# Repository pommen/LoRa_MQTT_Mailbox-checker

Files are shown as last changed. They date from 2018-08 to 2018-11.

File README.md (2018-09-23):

# LoRa_MQTT_Mailbox-checker
My version of a mailbox check using LoRa RFM95 module on a custom arduino pro mini with 18650battery. communicating with a ESP8266 

ISP pins on the board mounted on the mailbox is mirrored. If used, either burn boot loader before mounting the 328p. Or use dupoint wires to connect to the programmer.

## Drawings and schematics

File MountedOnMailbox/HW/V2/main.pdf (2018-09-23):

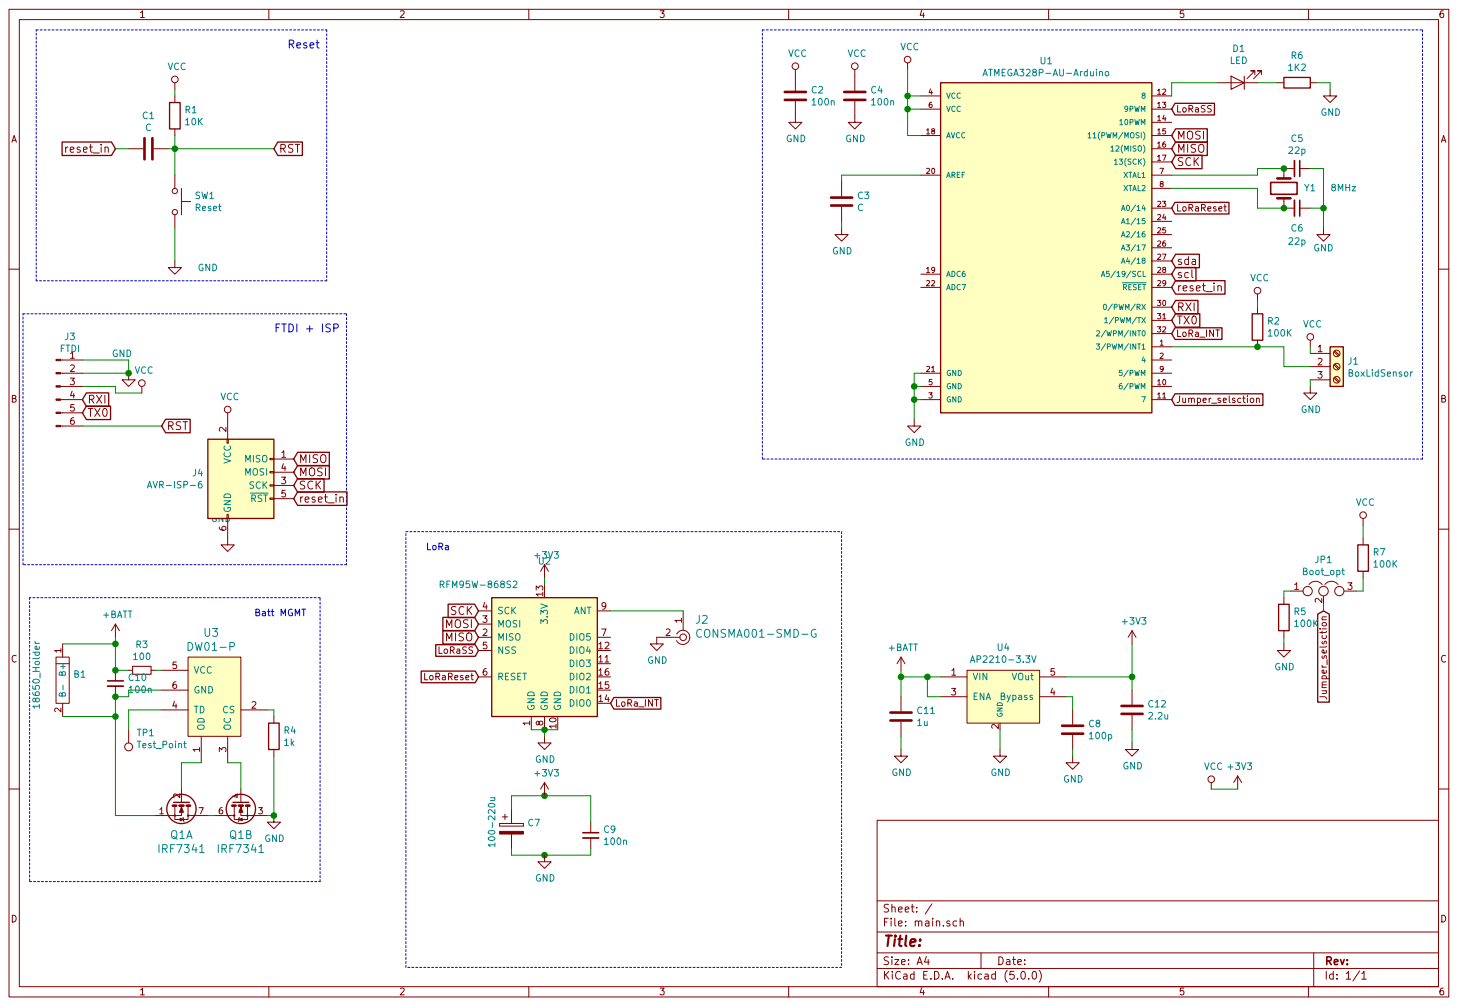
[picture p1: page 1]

scl sda Reset RST

2 SCK 3 MOSI 4 RST 5 GND

1 GND 10 DIO3 11 DIO4 12 3.3V 13 DIO0 14 DIO1 15 DIO2 16 MISO 2 MOSI 3 SCK 4 NSS 5 RESET 6 DIO5 7 GND
SCK

Id: 1/1 Title: File: main.sch Sheet: /

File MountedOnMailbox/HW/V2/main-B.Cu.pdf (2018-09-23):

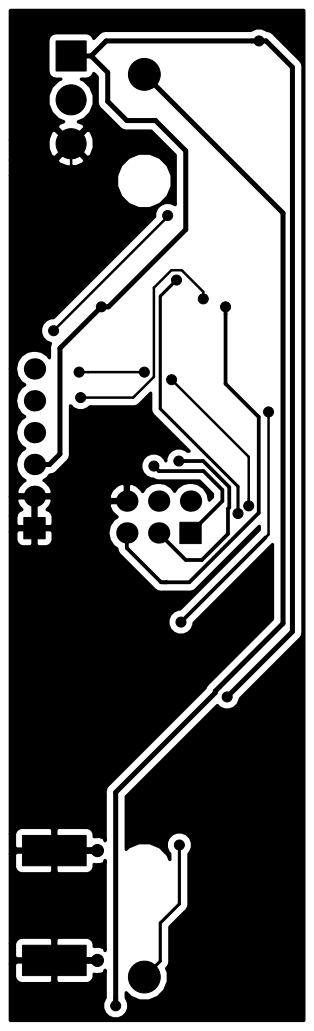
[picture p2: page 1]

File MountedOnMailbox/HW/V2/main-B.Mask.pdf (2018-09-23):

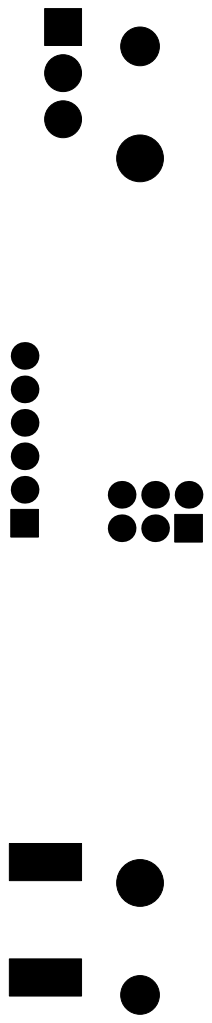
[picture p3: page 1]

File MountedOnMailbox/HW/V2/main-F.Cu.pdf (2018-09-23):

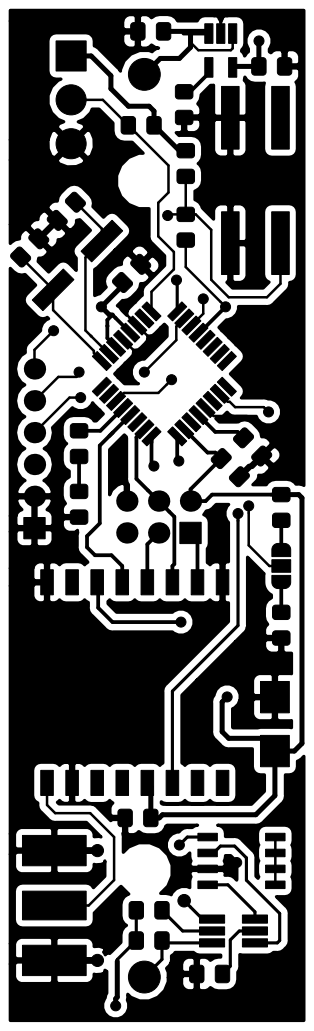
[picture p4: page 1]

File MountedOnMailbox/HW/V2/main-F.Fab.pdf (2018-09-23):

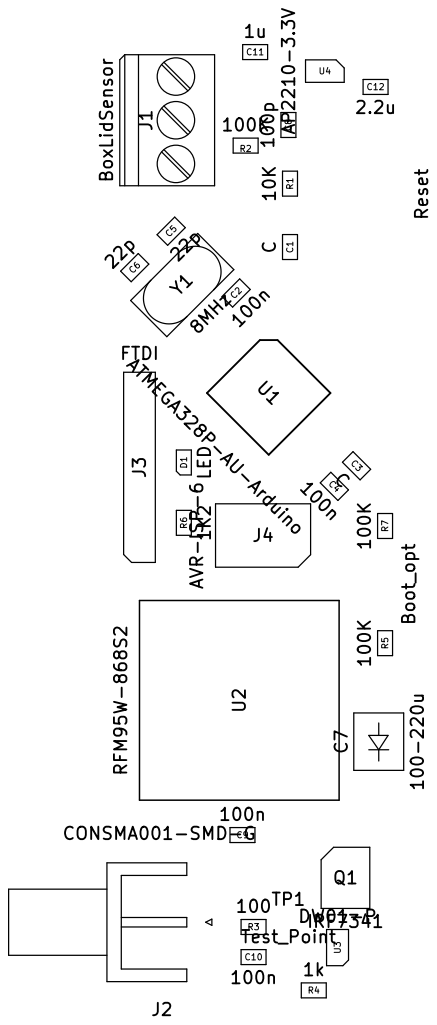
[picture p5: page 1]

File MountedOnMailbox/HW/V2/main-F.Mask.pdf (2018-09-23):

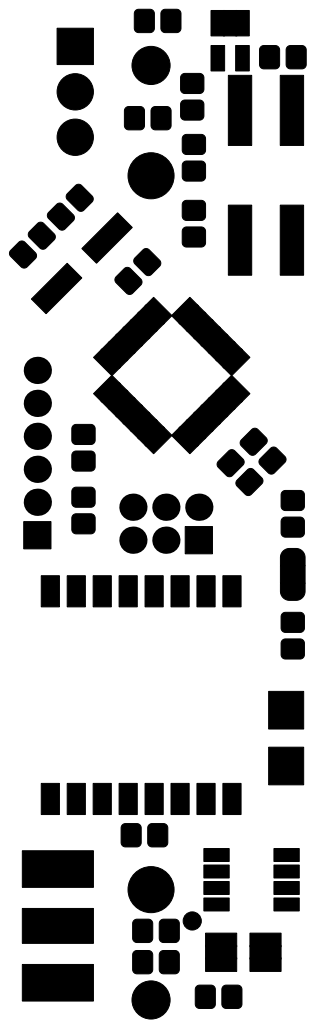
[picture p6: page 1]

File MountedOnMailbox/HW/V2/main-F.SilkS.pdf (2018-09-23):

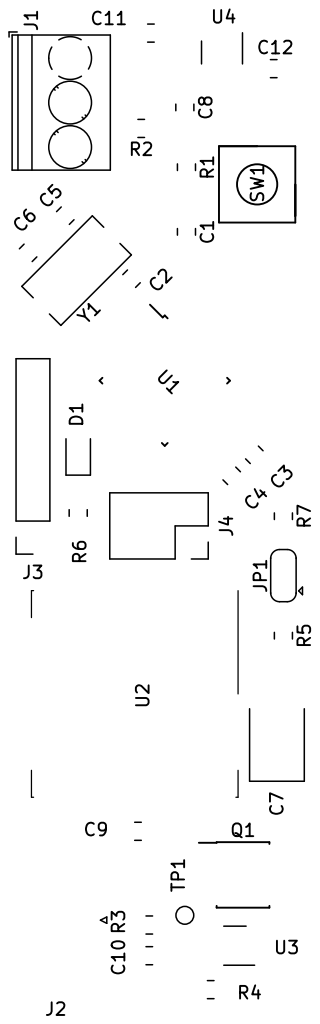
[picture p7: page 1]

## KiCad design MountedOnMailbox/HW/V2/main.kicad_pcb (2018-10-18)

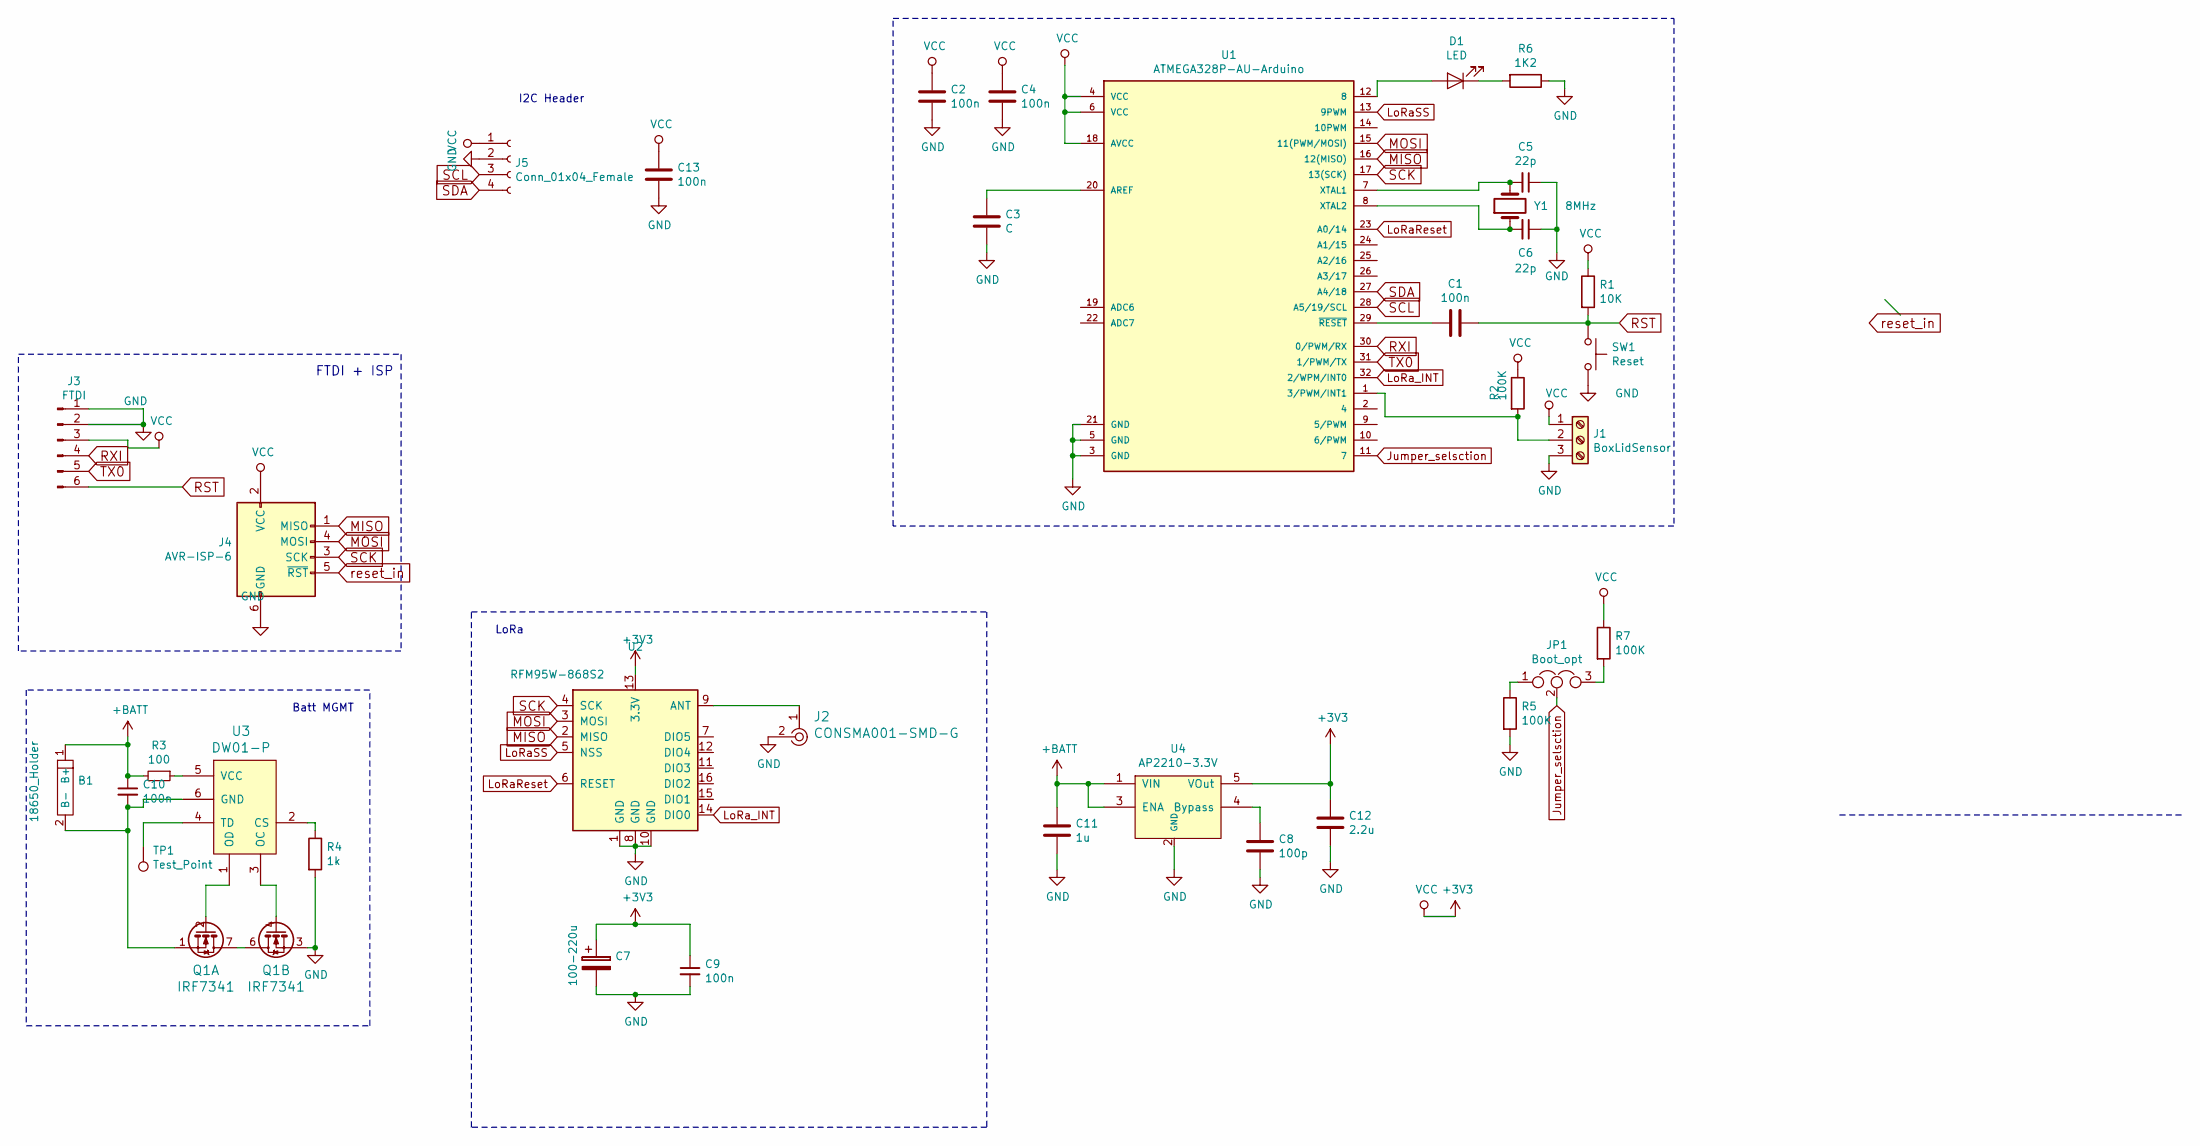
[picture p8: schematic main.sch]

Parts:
B1: 18650_Holder; 18650-PC2_holder
C1, C2, C4, C9, C10, C13: 100n; C_0805_2012Metric_Pad1.15x1.40mm_HandSolder
C3: C; C_0805_2012Metric_Pad1.15x1.40mm_HandSolder
C5, C6: 22p; C_0805_2012Metric_Pad1.15x1.40mm_HandSolder
C7: 100-220u; D_SMB
C8: 100p; C_0805_2012Metric_Pad1.15x1.40mm_HandSolder
C11: 1u; C_0805_2012Metric_Pad1.15x1.40mm_HandSolder
C12: 2.2u; C_0805_2012Metric_Pad1.15x1.40mm_HandSolder
D1: LED; LED_0805_2012Metric_Pad1.15x1.40mm_HandSolder
J1: BoxLidSensor; TerminalBlock_Phoenix_PT-1,5-3-3.5-H_1x03_P3.50mm_Horizontal
J2: CONSMA001-SMD-G; SMA_edge connector; MPN CONSMA001-SMD-G; Digi-Key_PN CONSMA001-SMD-G-ND
J3: FTDI; PinSocket_1x06_P2.54mm_Vertical
J4: AVR-ISP-6; PinSocket_2x03_P2.54mm_Vertical
J5: Conn_01x04_Female; PinHeader_1x04_P2.54mm_Vertical
JP1: Boot_opt; SolderJumper-3_P1.3mm_Open_RoundedPad1.0x1.5mm
Q1: IRF7341; SOIC-8_3.9x4.9mm_P1.27mm
R1: 10K; R_0805_2012Metric_Pad1.15x1.40mm_HandSolder
R2, R5, R7: 100K; R_0805_2012Metric_Pad1.15x1.40mm_HandSolder
R3: 100; R_0805_2012Metric_Pad1.15x1.40mm_HandSolder
R4: 1k; R_0805_2012Metric_Pad1.15x1.40mm_HandSolder
R6: 1K2; R_0805_2012Metric_Pad1.15x1.40mm_HandSolder
SW1: Reset; PushBTN KSC241G
TP1: Test_Point; TestPoint_Pad_D1.0mm
U1: ATMEGA328P-AU-Arduino; TQFP-32_7x7mm_P0.8mm
U2: RFM95W-868S2; HOPERF_RFM9XW_SMD
U3: DW01-P; TSOT-23-6_HandSoldering
U4: AP2210-3.3V; SOT-23-5_HandSoldering
Y1: 8MHz; Crystal_SMD_ECS_CSM3X-2Pin_7.6x4.1mm

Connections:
+3V3: C2.1, C4.1, C7.1, C9.1, C12.1, C13.1, J1.1, J3.3, J4.2 (VCC), J5.1, R1.1, R2.1, R7.1, U1.4 (VCC), U1.6 (VCC), U1.18 (AVCC), U2.13 (3.3V), U4.5 (VOut)
+BATT: B1.1 (B+), C10.1, C11.1, R3.2, U4.1 (VIN), U4.3 (ENA)
GND: C2.2, C3.2, C4.2, C5.1, C6.1, C7.2, C8.2, C9.2, C11.2, C12.2, C13.2, J1.3, J2.2, J3.1, J3.2, J4.6 (GND), J5.2, Q1.3, R4.2, R5.2, R6.1, SW1.2, U1.3 (GND), U1.5 (GND), U1.21 (GND), U2.1 (GND), U2.8 (GND), U2.10 (GND), U4.2 (GND)
Jumper_selsction: JP1.2, U1.11 (7)
LoRaReset: U1.23 (A0/14), U2.6 (RESET)
LoRaSS: U1.13 (9PWM), U2.5 (NSS)
LoRa_INT: U1.32 (2/WPM/INT0), U2.14 (DIO0)
MISO: J4.1 (MISO), U1.16 (12(MISO)), U2.2 (MISO)
MOSI: J4.4 (MOSI), U1.15 (11(PWM/MOSI)), U2.3 (MOSI)
unnamed: B1.2 (B-), C10.2, Q1.1, U3.6 (GND)
unnamed: C1.2, U1.29 (~RESET~)
unnamed: C3.1, U1.20 (AREF)
unnamed: C5.2, U1.7 (XTAL1), Y1.2
unnamed: C6.2, U1.8 (XTAL2), Y1.1
unnamed: C8.1, U4.4 (Bypass)
unnamed: D1.1 (K), R6.2
unnamed: D1.2 (A), U1.12 (8)
unnamed: J1.2, R2.2, U1.1 (3/PWM/INT1)
unnamed: J2.1, U2.9 (ANT)
unnamed: JP1.1, R5.1
unnamed: JP1.3, R7.2
unnamed: Q1.2, U3.1 (OD)
unnamed: Q1.4, U3.3 (OC)
unnamed: Q1.5, Q1.6, Q1.7, Q1.8
unnamed: R3.1, U3.5 (VCC)
unnamed: R4.1, U3.2 (CS)
unnamed: TP1.1, U3.4 (TD)
RST: C1.1, J3.6, R1.2, SW1.1
RXI: J3.4, U1.30 (0/PWM/RX)
SCK: J4.3 (SCK), U1.17 (13(SCK)), U2.4 (SCK)
SCL: J5.3, U1.28 (A5/19/SCL)
SDA: J5.4, U1.27 (A4/18)
TX0: J3.5, U1.31 (1/PWM/TX)
reset_in: J4.5 (~RST)

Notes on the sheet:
FTDI + ISP
Batt MGMT
LoRa
I2C Header

Board: 2 copper layers, 36 parts (1 on the bottom side), 33 nets, no tracks yet.

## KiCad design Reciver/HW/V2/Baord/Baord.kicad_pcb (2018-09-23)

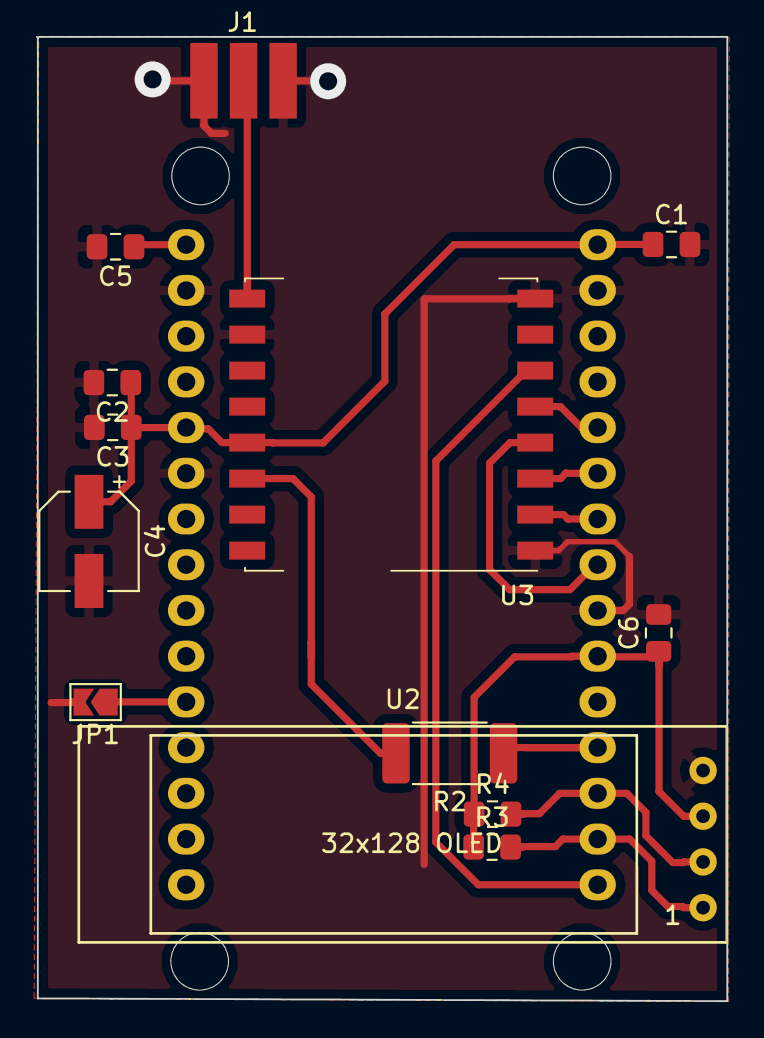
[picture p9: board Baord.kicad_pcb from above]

Board: 2 copper layers, 38.4 x 53.6 mm, 14 parts (1 on the bottom side), 14 nets.

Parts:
C1, C2, C5, C6: 100n; C_0805_2012Metric_Pad1.15x1.40mm_HandSolder
C3: C; C_0805_2012Metric_Pad1.15x1.40mm_HandSolder
C4: CP; CP_Elec_5x5.9
J1: Edge_Connector; SMA_edge connector
JP1: Jumper; SolderJumper-2_P1.3mm_Open_TrianglePad1.0x1.5mm
R2: 0R; R_2512_6332Metric_Pad1.52x3.35mm_HandSolder
R3, R4: 10K; R_0805_2012Metric_Pad1.15x1.40mm_HandSolder
U1: NodeMCU_1.0_(ESP-12E); NodeMCU_Amica_R2
U2: OLED_128x32_i2c; OLED_128x32_I2C
U3: RFM95W-868S2; HOPERF_RFM9XW_SMD

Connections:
CS: U1.20, U3.5
GND: C1.2, C2.2, C3.2, C4.2, C5.2, C6.2, J1.2, JP1.2, U1.10, U1.14, U1.17, U1.24, U2.4, U3.1, U3.8, U3.10
I2C_SCL: R4.2, U1.28, U2.2
I2C_SDA: R3.2, U1.29, U2.1
INT: R2.1, U1.27
MISO: U1.22, U3.2
MOSI: U1.21, U3.3
unnamed: C5.1, U1.15
unnamed: J1.1, U3.9
unnamed: JP1.1, U1.5
unnamed: R2.2, U3.14
RESET: U1.30, U3.6
SCK: U1.23, U3.4
VCC: C1.1, C2.1, C3.1, C4.1, C6.1, R3.1, R4.1, U1.11, U1.16, U1.25, U2.3, U3.13

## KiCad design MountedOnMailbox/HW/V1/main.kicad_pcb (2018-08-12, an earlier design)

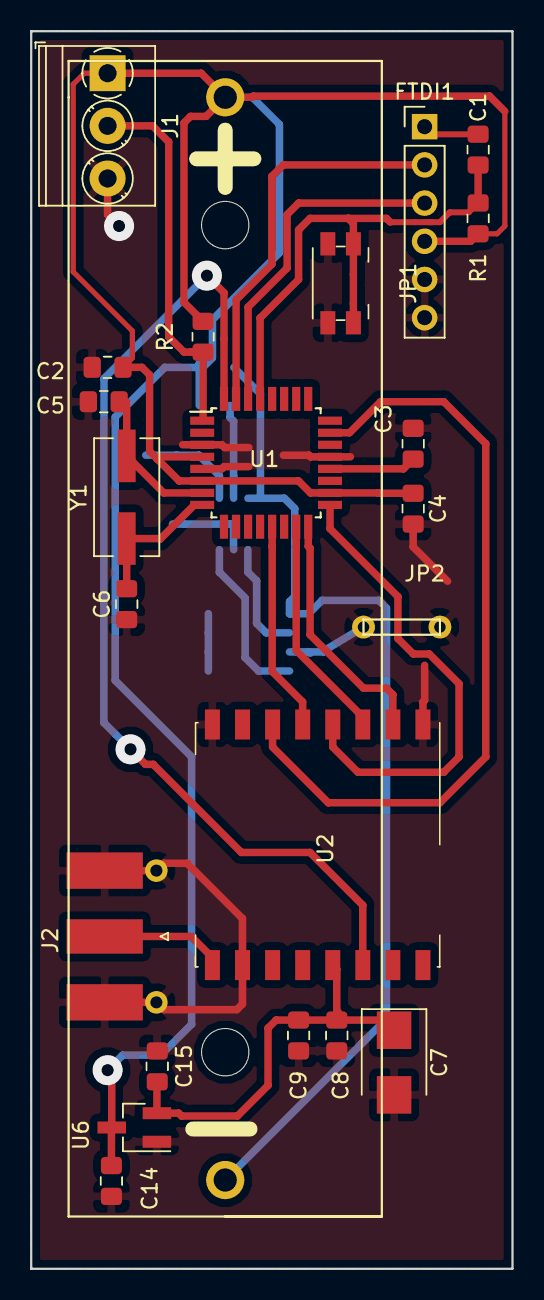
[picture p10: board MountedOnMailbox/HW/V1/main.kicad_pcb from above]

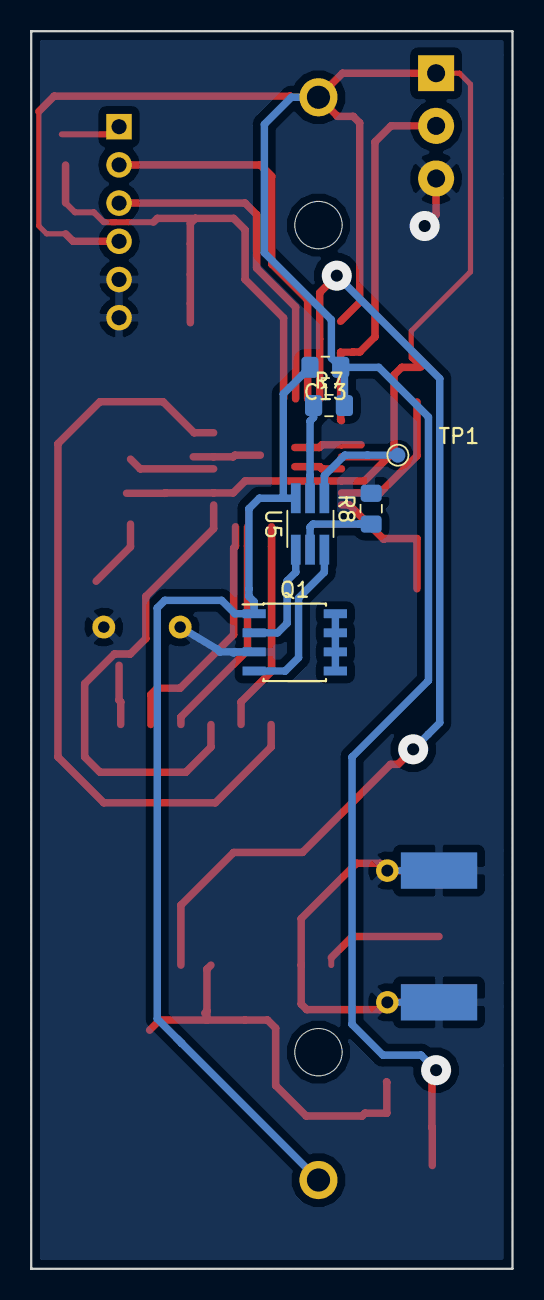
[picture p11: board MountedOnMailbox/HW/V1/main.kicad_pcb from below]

Board: 2 copper layers, 32.0 x 82.3 mm, 29 parts (6 on the bottom side), 25 nets.

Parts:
B1: 18650_Holder; 18650-PC2_holder
C1, C2, C3, C4: C; C_0805_2012Metric_Pad1.15x1.40mm_HandSolder
C5, C6: 22p; C_0805_2012Metric_Pad1.15x1.40mm_HandSolder
C7: 100-220u; D_SMB
C8: 10u; C_0805_2012Metric_Pad1.15x1.40mm_HandSolder
C9, C13: 100n; C_0805_2012Metric_Pad1.15x1.40mm_HandSolder
C14, C15: 1u; C_0805_2012Metric_Pad1.15x1.40mm_HandSolder
FTDI1: FTDI; PinHeader_1x06_P2.54mm_Vertical
J1: BoxLidSensor; TerminalBlock_Phoenix_PT-1,5-3-3.5-H_1x03_P3.50mm_Horizontal
J2: CONSMA001-SMD-G; SMA_Molex_73251-1153_EdgeMount_Horizontal
JP1: Jumper; Panasonic_EVQPUJ_EVQPUA
JP2: Jumper; JUMPER_5MM
Q1: IRF7341; SOIC-8_3.9x4.9mm_P1.27mm
R1: 10K; R_0805_2012Metric_Pad1.15x1.40mm_HandSolder
R2: 100K; R_0805_2012Metric_Pad1.15x1.40mm_HandSolder
R7: 100; R_0805_2012Metric_Pad1.15x1.40mm_HandSolder
R8: 1k; R_0805_2012Metric_Pad1.15x1.40mm_HandSolder
TP1: Test_Point; TestPoint_Pad_D1.0mm
U1: ATMEGA328P; TQFP-32_7x7mm_P0.8mm
U2: RFM95W-868S2; HOPERF_RFM9XW_SMD
U5: DW01-P; TSOT-23-6_HandSoldering
U6: XC6206P332MR; SOT-23_Handsoldering
Y1: 8MHz; Crystal_SMD_ECS_CSM3X-2Pin_7.6x4.1mm

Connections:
+3V3: C7.1, C8.1, C9.1, C15.1, U2.13, U6.2
+BATT: B1.1, C2.1, C4.1, C13.1, C14.1, FTDI1.4, J1.1, R1.1, R2.1, R7.2, U1.4, U1.6, U1.18, U6.3
GND: C2.2, C3.2, C4.2, C5.1, C6.1, C7.2, C8.2, C9.2, C14.2, C15.2, FTDI1.5, FTDI1.6, J1.3, J2.2, JP1.2, JP2.1, JP2.2, Q1.3, R8.2, U1.3, U1.5, U1.21, U2.1, U2.8, U2.10, U6.1
LoRaReset: U1.23, U2.6
LoRaSS: U1.13, U2.5
LoRa_INT: U1.32, U2.14
MISO: U1.16, U2.2
MOSI: U1.15, U2.3
unnamed: B1.2, C13.2, Q1.1, U5.6
unnamed: C3.1, U1.20
unnamed: C5.2, U1.7, Y1.2
unnamed: C6.2, U1.8, Y1.1
unnamed: J1.2, R2.2, U1.1
unnamed: J2.1, U2.9
unnamed: Q1.2, U5.1
unnamed: Q1.4, U5.3
unnamed: Q1.5, Q1.6, Q1.7, Q1.8
unnamed: R7.1, U5.5
unnamed: R8.1, U5.2
unnamed: TP1.1, U5.4
RST: C1.1, FTDI1.1
RXI: FTDI1.3, U1.30
SCK: U1.17, U2.4
TX0: FTDI1.2, U1.31
reset_in: C1.2, JP1.1, R1.2, U1.29

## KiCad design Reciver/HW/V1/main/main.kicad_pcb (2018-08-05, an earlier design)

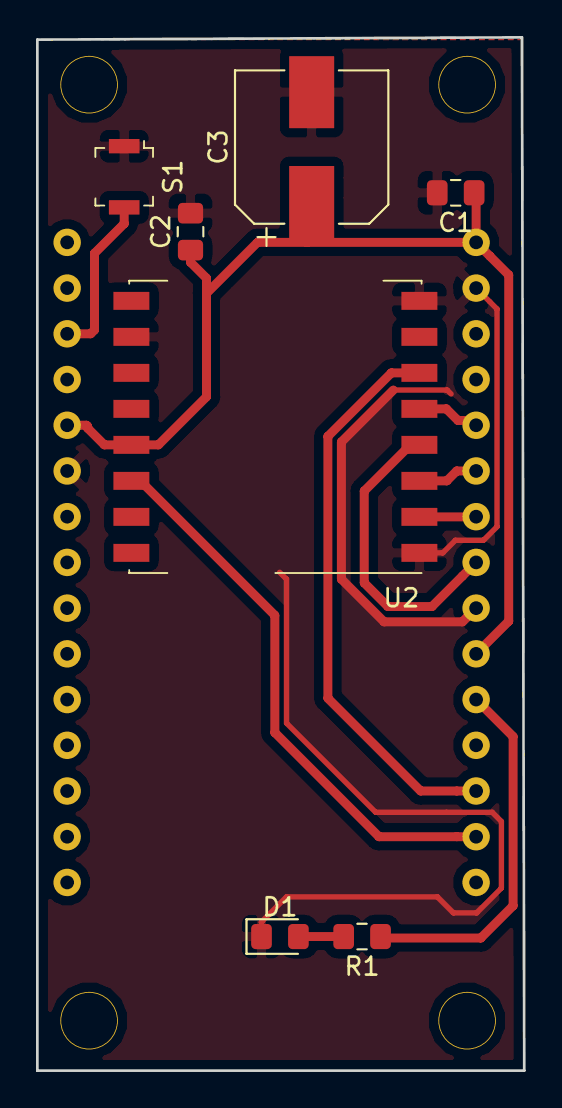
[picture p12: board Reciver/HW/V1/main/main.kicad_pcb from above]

Board: 2 copper layers, 27.1 x 57.4 mm, 8 parts (1 on the bottom side), 11 nets.

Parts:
C1, C2: C; C_0805_2012Metric_Pad1.15x1.40mm_HandSolder
C3: CP; CP_Elec_8x6.7
D1: LED; LED_0805_2012Metric_Pad1.15x1.40mm_HandSolder
R1: 1K; R_0805_2012Metric_Pad1.15x1.40mm_HandSolder
S1: GPTS203211B; Switch_Tactile_SMD_B3U-1000P
U1: NodeMCU_1.0_(ESP-12E); NodeMCU-LoLinV3
U2: RFM95W-868S2; HOPERF_RFM9XW_SMD

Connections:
CS: U1.20, U2.5
GND: C1.2, C2.2, C3.2, D1.1, S1.1, U1.10, U1.14, U1.17, U1.24, U2.1, U2.8, U2.10
INT: U1.29, U2.14
MISO: U1.22, U2.2
MOSI: U1.21, U2.3
unnamed: D1.2, R1.2
unnamed: R1.1, U1.26
unnamed: S1.2, U1.13
RESET: U1.28, U2.6
SCK: U1.23, U2.4
VCC: C1.1, C2.1, C3.1, U1.11, U1.16, U1.25, U2.13

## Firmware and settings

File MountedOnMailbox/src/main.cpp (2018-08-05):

// LoRa 9x_TX
// -*- mode: C++ -*-
// Example sketch showing how to create a simple messaging client (transmitter)
// with the RH_RF95 class. RH_RF95 class does not provide for addressing or
// reliability, so you should only use RH_RF95 if you do not need the higher
// level messaging abilities.
// It is designed to work with the other example LoRa9x_RX
//https://learn.adafruit.com/adafruit-rfm69hcw-and-rfm96-rfm95-rfm98-lora-packet-padio-breakouts/rfm9x-test
//http://forum.arduino.cc/index.php?topic=313587.0

#include <Arduino.h>
#include <avr/power.h>
#include <SPI.h>
#include <RH_RF95.h>
#include <LowPower.h>
#define RFM95_CS 9
#define RFM95_RST A0
#define RFM95_INT 2
#define boxLidPin 3
// Change to 434.0 or other frequency, must match RX's freq!
#define RF95_FREQ 868.0

// Singleton instance of the radio driver
RH_RF95 rf95(RFM95_CS, RFM95_INT);

//protos
void wakeup();
void sleep();
int battVolt();
void whattoSend();

//Vars:
bool LidHasBeenOpened = 0;    //flag for keeping track if the mailbox lid has been opened.
int coolDownTimer = 0;        //debounce timer for the lid, so we dont spam.
bool messageSentFlag = false; //flag for keeping track if we have sent something

//This is the struct we send
struct dataStruct
{
  float BatteryVoltage;
  bool lidOpened;
  int ID;

} myData;

byte tx_buf[sizeof(myData)] = {0};

void setup()
{
  pinMode(RFM95_RST, OUTPUT);
  pinMode(boxLidPin, INPUT);
  digitalWrite(RFM95_RST, HIGH);

  Serial.begin(9600);
  delay(100);

  Serial.println("Mailbox lid detector...With LoRa! :D ");

  // manual reset
  digitalWrite(RFM95_RST, LOW);
  delay(10);
  digitalWrite(RFM95_RST, HIGH);
  delay(10);

  while (!rf95.init())
  {
    Serial.println("LoRa radio init failed");
    while (1)
      ;
  }
  Serial.println("LoRa radio init OK!");

  // Defaults after init are 434.0MHz, modulation GFSK_Rb250Fd250, +13dbM
  if (!rf95.setFrequency(RF95_FREQ))
  {
    Serial.println("setFrequency failed");
    while (1)
      ;
  }
  Serial.print("Set Freq to: ");
  Serial.println(RF95_FREQ);

  // Defaults after init are 434.0MHz, 13dBm, Bw = 125 kHz, Cr = 4/5, Sf = 128chips/symbol, CRC on

  // The default transmitter power is 13dBm, using PA_BOOST.
  // If you are using RFM95/96/97/98 modules which uses the PA_BOOST transmitter pin, then
  // you can set transmitter powers from 5 to 23 dBm:
  rf95.setTxPower(23, false);

  power_twi_disable(); // TWI (I2C) disabled
  power_adc_disable(); // ADC converter disabled

  myData.ID = 21; //21  är brevlådan
  //attachInterrupt(digitalPinToInterrupt(boxLidPin), wakeup, FALLING);
}

void loop()
{

  if (LidHasBeenOpened && !messageSentFlag)
  {
    whattoSend();
  }

  //Serial.println("Waiting for reply...");

  //going to sleep

  if (millis() - coolDownTimer > 30000)
  {
    sleep();
  }
  /* else
  {
    Serial.println(millis() - coolDownTimer);
  } */
}

void whattoSend()
{
  messageSentFlag = true;
  uint8_t buf[RH_RF95_MAX_MESSAGE_LEN];
  uint8_t len = sizeof(buf);
  myData.BatteryVoltage = battVolt() / 1000.00;
  myData.lidOpened = LidHasBeenOpened;
  //myData.counter = counter++;

  Serial.println("Sending to rf95_server");
  byte zize = sizeof(myData);
  Serial.println("Sending...");
  delay(10);

  memcpy(tx_buf, &myData, sizeof(myData));
  rf95.send((uint8_t *)tx_buf, zize);

  Serial.println("Waiting for packet to complete...");
  rf95.sleep();
  rf95.waitPacketSent();
  rf95.sleep();
  if (rf95.waitAvailableTimeout(1000))
  {
    // Should be a reply message for us now
    if (rf95.recv(buf, &len))
    {
      Serial.print("Got reply: ");
      Serial.println((char *)buf);
      Serial.print("RSSI: ");
      Serial.println(rf95.lastRssi(), DEC);
    }
    else
    {
      Serial.println("Receive failed");
    }
  }
  else
  {
    Serial.println("No reply, is there a listener around?");
  }
  // delay(1000);
}

void sleep()
{
  Serial.println("Going to sleep");
  delay(200);

  messageSentFlag = false;
  LidHasBeenOpened = false;
  rf95.sleep();

  attachInterrupt(digitalPinToInterrupt(boxLidPin), wakeup, FALLING);
  delay(200);
  // LowPower.powerDown(SLEEP_1S, ADC_OFF, BOD_OFF);
  LowPower.powerDown(SLEEP_FOREVER, ADC_OFF, BOD_OFF);
  detachInterrupt(digitalPinToInterrupt(boxLidPin));
  LidHasBeenOpened = true;
  LidHasBeenOpened = true;
  coolDownTimer = millis();
  Serial.println("Woken up");
}

void wakeup()
{
  //delay(200);
}

int battVolt()
{
  power_adc_enable(); // ADC converter
  long result = 0;

  // Read 1.1V reference against AVcc
  // set the reference to Vcc and the measurement to the internal 1.1V reference
#if defined(__AVR_ATmega32U4__) || defined(__AVR_ATmega1280__) || defined(__AVR_ATmega2560__)
  ADMUX = _BV(REFS0) | _BV(MUX4) | _BV(MUX3) | _BV(MUX2) | _BV(MUX1);
#elif defined(__AVR_ATtiny24__) || defined(__AVR_ATtiny44__) || defined(__AVR_ATtiny84__)
  ADMUX = _BV(MUX5) | _BV(MUX0);
#elif defined(__AVR_ATtiny25__) || defined(__AVR_ATtiny45__) || defined(__AVR_ATtiny85__)
  ADMUX = _BV(MUX3) | _BV(MUX2);
#else
  ADMUX = _BV(REFS0) | _BV(MUX3) | _BV(MUX2) | _BV(MUX1);
#endif

  delay(2);            // Wait for Vref to settle
  ADCSRA |= _BV(ADSC); // Start conversion
  while (bit_is_set(ADCSRA, ADSC))
    ; // measuring

  uint8_t low = ADCL;  // must read ADCL first - it then locks ADCH
  uint8_t high = ADCH; // unlocks both

  result = (high << 8) | low;

  result = 1125300L / result; // Calculate Vcc (in mV); 1125300 = 1.1*1023*1000
  power_adc_disable();        // ADC converter

  return result;
}

/*
   Name: powerDown
 * Description: Putting microcontroller into power down state. This is
 *			   the lowest current consumption state. Use this together with
 *			   external pin interrupt to wake up through external event
 *			   triggering (example: RTC clockout pin, SD card detect pin).
 *
 * Argument   Description
 * =========    ===========
 * 1. period     Duration of low power mode. Use SLEEP_FOREVER to use other wake
 *				up resource:
 *				(a) SLEEP_15MS - 15 ms sleep
 *				(b) SLEEP_30MS - 30 ms sleep
 *				(c) SLEEP_60MS - 60 ms sleep
 *				(d) SLEEP_120MS - 120 ms sleep
 *				(e) SLEEP_250MS - 250 ms sleep
 *				(f) SLEEP_500MS - 500 ms sleep
 *				(g) SLEEP_1S - 1 s sleep
 *				(h) SLEEP_2S - 2 s sleep
 *				(i) SLEEP_4S - 4 s sleep
 *				(j) SLEEP_8S - 8 s sleep
 *				(k) SLEEP_FOREVER - Sleep without waking up through WDT
 *
 * 2. adc		ADC module disable control. Turning off the ADC module is
 *				basically removing the purpose of this low power mode.
 *				(a) ADC_OFF - Turn off ADC module
 *				(b) ADC_ON - Leave ADC module in its default state
 *
 * 3. bod		Brown Out Detector (BOD) module disable control:
 *				(a) BOD_OFF - Turn off BOD module
 *				(b) BOD_ON - Leave BOD module in its default state
 *

 Enabling:
   power_adc_enable(); // ADC converter
   power_spi_enable(); // SPI
   power_usart0_enable(); // Serial (USART)
   power_timer0_enable(); // Timer 0
   power_timer1_enable(); // Timer 1
   power_timer2_enable(); // Timer 2
   power_twi_enable(); // TWI (I2C)

   Disabling:
   power_adc_disable(); // ADC converter
   power_spi_disable(); // SPI
   power_usart0_disable();// Serial (USART)
   power_timer0_disable();// Timer 0
   power_timer1_disable();// Timer 1
   power_timer2_disable();// Timer 2
   power_twi_disable(); // TWI (I2C)
*/

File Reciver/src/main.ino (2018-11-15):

//#include <Arduino.h>
// Arduino9x_RX
// -*- mode: C++ -*-
// Example sketch showing how to create a simple messaging client (receiver)
// with the RH_RF95 class. RH_RF95 class does not provide for addressing or
// reliability, so you should only use RH_RF95 if you do not need the higher
// level messaging abilities.
// It is designed to work with the other example Arduino9x_TX
//https://learn.adafruit.com/adafruit-rfm69hcw-and-rfm96-rfm95-rfm98-lora-packet-padio-breakouts/rfm9x-test
//http://forum.arduino.cc/index.php?topic=313587.0
//https://www.instructables.com/id/ESP8266-GMail-Sender/

#include <SPI.h>
#include <RH_RF95.h>
#include <ESP8266WiFi.h>
#include "Gsender.h"

#pragma region Globals
const char *ssid = "mywifissid";         // WIFI network name
const char *password = "*mywifipassword"; // WIFI network password
uint8_t connection_state = 0;         // Connected to WIFI or not
uint16_t reconnect_interval = 10000;  // If not connected wait time to try again
#pragma endregion Globals
/*
  WeMos D1          RFM9x Module
  GPIO12 (D6) <----> MISO
  GPIO13 (D7) <----> MOSI
  GPIO14 (D5) <----> CLK
  GPIO15 (D8) <----> DIO0/D2 OR DIO1/D3 OR DIO2/D4
  GPIO16 (D0) <----> SEL Chip Select (depending on bottom solder PAD position) 
  */

int RFM95_CS = D8; 
int RFM95_RST = D0;
int RFM95_INT = D1;

// Change to 434.0 or other frequency, must match RX's freq!
#define RF95_FREQ 868.0

// Singleton instance of the radio driver
RH_RF95 rf95(RFM95_CS, RFM95_INT);

// Blinky on receipt
//#define LED 13
int LED = LED_BUILTIN;
struct dataStruct
{
    float BatteryVoltage;
    bool lidOpened;
    int ID;
    long int rest;

} myData;

//Protos:
//void Awaits();
//uint8_t WiFiConnect(const char *nSSID, const char *nPassword);

uint8_t WiFiConnect(const char *nSSID = nullptr, const char *nPassword = nullptr)
{
    static uint16_t attempt = 0;
    Serial.print("Connecting to ");
    if (nSSID)
    {
        WiFi.begin(nSSID, nPassword);
        Serial.println(nSSID);
    }
    else
    {
        WiFi.begin(ssid, password);
        Serial.println(ssid);
    }

    uint8_t i = 0;
    while (WiFi.status() != WL_CONNECTED && i++ < 50)
    {
        delay(200);
        Serial.print(".");
    }
    ++attempt;
    Serial.println("");
    if (i == 51)
    {
        Serial.print("Connection: TIMEOUT on attempt: ");
        Serial.println(attempt);
        if (attempt % 2 == 0)
            Serial.println("Check if access point available or SSID and Password\r\n");
        return false;
    }
    Serial.println("Connection: ESTABLISHED");
    Serial.print("Got IP address: ");
    Serial.println(WiFi.localIP());
    return true;
}
void setup()
{
    pinMode(LED, OUTPUT);
    pinMode(RFM95_RST, OUTPUT);
    digitalWrite(RFM95_RST, HIGH);

    Serial.begin(9600);
    delay(100);
    connection_state = WiFiConnect();
    if (!connection_state) // if not connected to WIFI
        Awaits();          // constantly trying to connect

    Serial.println("Lora Reciver and Gmail sender :D");

    // manual reset
    digitalWrite(RFM95_RST, LOW);
    delay(10);
    digitalWrite(RFM95_RST, HIGH);
    delay(10);

    while (!rf95.init())
    {
        Serial.println("LoRa radio init failed");
    }
    Serial.println("LoRa radio init OK!");

    // Defaults after init are 434.0MHz, modulation GFSK_Rb250Fd250, +13dbM
    if (!rf95.setFrequency(RF95_FREQ))
    {
        Serial.println("setFrequency failed");
    }
    Serial.print("Set Freq to: ");
    Serial.println(RF95_FREQ);

    // Defaults after init are 434.0MHz, 13dBm, Bw = 125 kHz, Cr = 4/5, Sf = 128chips/symbol, CRC on

    // The default transmitter power is 13dBm, using PA_BOOST.
    // If you are using RFM95/96/97/98 modules which uses the PA_BOOST transmitter pin, then
    // you can set transmitter powers from 5 to 23 dBm:
    rf95.setTxPower(23, false);
    Serial.println("Setup Done!");
}

void loop()
{
    if (rf95.available())
    {
        // Should be a message for us now
        uint8_t buf[RH_RF95_MAX_MESSAGE_LEN];
        uint8_t len = sizeof(buf);

        if (rf95.recv(buf, &len))
        {
            digitalWrite(LED, HIGH);
            RH_RF95::printBuffer("Received: ", buf, len);
            Serial.print("Got: ");

            memcpy(&myData, buf, sizeof(myData));
            Serial.println("");

            Serial.print("BatteryVoltage: ");
            Serial.print(myData.BatteryVoltage);

            Serial.print("  lidOened: ");
            Serial.print(myData.lidOpened);

            Serial.print("  ID: ");
            Serial.println(myData.ID);

            Serial.print("RSSI: ");
            Serial.println(rf95.lastRssi(), DEC);

            // Send a reply
            uint8_t data[] = "And hello back to you";
            rf95.send(data, sizeof(data));
            rf95.waitPacketSent();
            Serial.println("Sent a reply");
            digitalWrite(LED, LOW);
        }
        else
        {
            Serial.println("Receive failed");
        }
    }

    if (myData.lidOpened)
    {
        sendMail();
        myData.lidOpened = 0;
    }
}

void sendMail()
{
    String messageString = "Battery Voltage: ";
    messageString += String(myData.BatteryVoltage);
    messageString += " Volt";
    Gsender *gsender = Gsender::Instance(); // Getting pointer to class instance
    String subject = "Mailman is here :D";
    if (gsender->Subject(subject)->Send("pommengt@gmail.com", messageString))
    {
        Serial.println("Message send.");
    }
    else
    {
        Serial.print("Error sending message: ");
        Serial.println(gsender->getError());
    }
}
void Awaits()
{
    uint32_t ts = millis();
    while (!connection_state)
    {
        delay(50);
        if (millis() > (ts + reconnect_interval) && !connection_state)
        {
            connection_state = WiFiConnect();
            ts = millis();
        }
    }
}

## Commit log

2018-08-04 The sender module, first upload
    [Battery.sch, main.kicad_pcb, main.sch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]
2018-08-05 revicer, bad NODEMCU footprint
    [main.kicad_pcb, main.sch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]
2018-08-05 Better foorprint
    [_saved_main.sch, main.kicad_pcb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]
2018-08-12 layout
    kicad
    [Battery.sch, _saved_main.sch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]
2018-10-18 Better layout
    And i2c header
    [main.kicad_pcb, main.sch]
